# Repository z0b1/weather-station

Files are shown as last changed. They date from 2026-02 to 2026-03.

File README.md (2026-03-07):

# weather-station
I'm presenting my project of a Field Weather Station containing anemometers and wind direction sensors, also ambient temp. and humidity sensors with a UHF transmitter in the field and an at home reciever(rtl-sdr). This also includes an RPi 4 (4GB RAM) that is recieving satellite images and displaying them in a mobile phone app.
# Why a weather station-Short Story
I live in the countryside and my family has large fruit plantations. By the microclimate of my area strong frosts in the spring time are common, that quite often hurts the fruits. We solve this issue by turning on our watering systems(the ground water keeps around 12 degrees Celsius at all times), but also by using air heaters to warm the area. So instead of waking up every 30 minutes to check the temps and having to go outside this idea was born. Main goal is that the weather station sends me phone notifications to a custom website/app. The weather station is located atleast 500m away from the house so the trick was getting reliable power, which I solved using a solar panel and a Lead Acid battery.
# How it functions 
Using an Arduino Nano I read the data from the sensors and send it with my UHF transmitter using ASK modulation(to be changed to FSK if too much interferences). At home using a reciever and an RPi 4 Model B (4GB), RTL SDR V4 and a homemade quadrifillar helix antenna to recieve satellite images and a Nagoya antenna for the UHF signals. Compare it and display on the website/app using the RPi.
# What might be added 
Using local LLM's to recognize cloud and other patterns to predict weather more accurately.

# Pictures
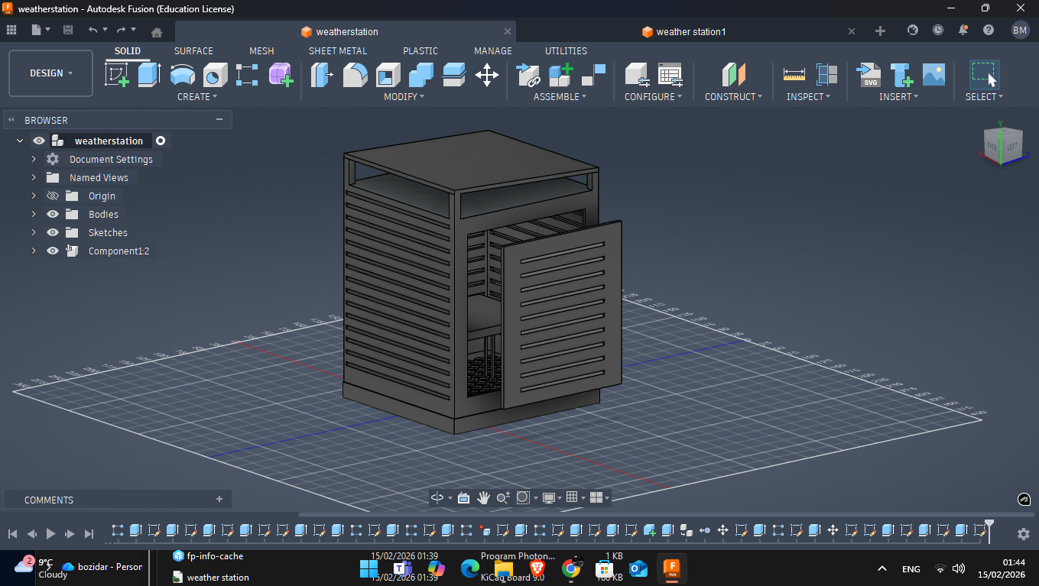
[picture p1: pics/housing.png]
housing

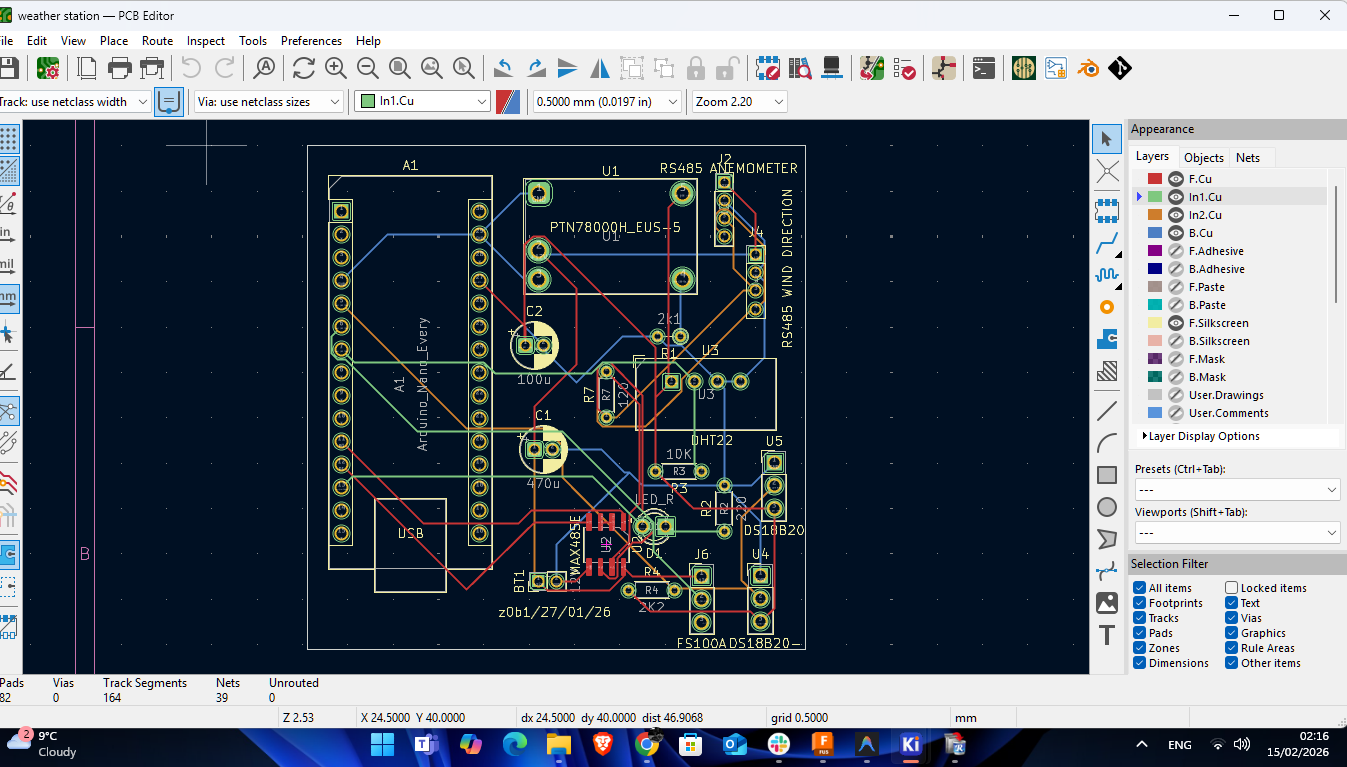
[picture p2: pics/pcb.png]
pcb

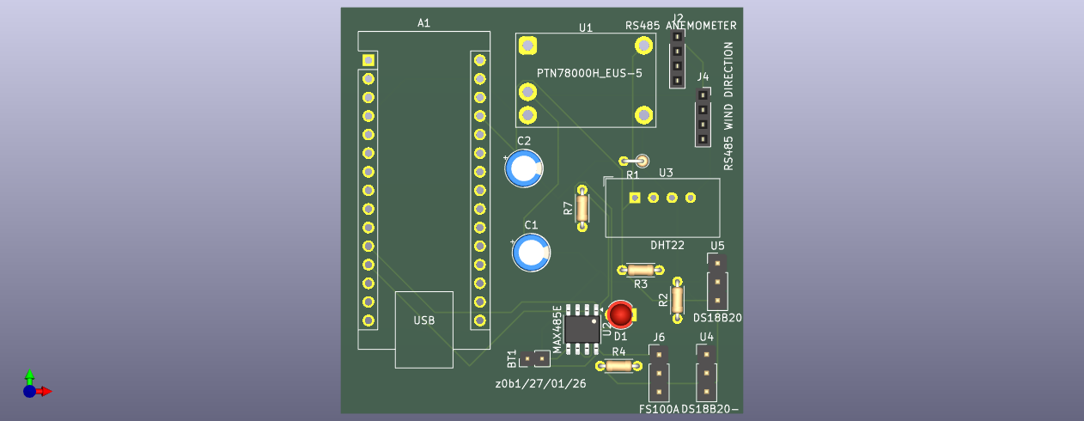
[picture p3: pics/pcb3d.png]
pcb3d


# NAPRED ZVEZDO

# The BOM

| Reference | Qty | Value | Price | Link | Info | Datasheet |
|---|---|---|---|---|---|---|
| A1 | 1 | Arduino Nano | € 5.16 | [Link](https://www.aliexpress.com/item/1005009848194286.html) | | [Link](https://content.arduino.cc/assets/NANOEveryV3.0_sch.pdf) |
| AE1 | 1 | Antenna Shielded SMA | € 0.00 | [Link](https://www.aliexpress.com/item/1005008813991595.html) | I already have | ~ |
| AE2 | 2 | Nagoya NA-771 | € 7.47 | [Link](https://www.aliexpress.com/item/1005008660133810.html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) | High Gain Handheld Antenna | ~ |
| BT1 | 1 | 12V 5Ah Lead Acid | € 11.84 | [Link](https://borikplus.rs/proizvodi/olovne-baterije/ritar-rt1250-olovna-vrla-baterija-12v-5ah/) | Alternative capacity | ~ |
| C1 | 1 | 470uF | € 0.00 | [Link](https://www.aliexpress.com/item/1005008244407175.html) | I already have | ~ |
| C2 | 1 | 100uF | € 0.00 | [Link](https://www.aliexpress.com/item/1005005661484224.html) | I already have | ~ |
| C3 | 1 | 2pF | - | | | ~ |
| C4 | 1 | 2.2pF | - | | | ~ |
| C5 | 1 | 10pF | - | | | ~ |
| C6 | 1 | 470pF | - | | | ~ |
| D1 | 1 | LED_R | € 0.00 | [Link](https://www.aliexpress.com/item/1005010315277808.html) | I already have | ~ |
| J1, J2 | 1 | RS485 ANEMOMETER | € 26.53 | [Link](https://www.aliexpress.com/item/1005007059408469.html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) | RS485 type | ~ |
| J4 | 1 | RS485 WIND DIRECTION | € 23.82 | [Link](https://www.aliexpress.com/item/1005007059408469.html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) | RS485 type | ~ |
| U4 | 1 | SDLA12TA | € 6.86 | [Link](https://www.aliexpress.com/item/1005006641063540.html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) | | [Link](https://easyeda.com/component/451d05428ff8431fb9c594829dfd0fbf) |
| R1 | 1 | 2k1 | € 0.00 | [Link](https://www.aliexpress.com/item/1005010688244614.html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) | I already have | ~ |
| R2 | 1 | 220| - | | | ~ |
| R3, R6 | 2 | 10K | - | | | ~ |
| R5 | 1 | 47K | - | | | ~ |
| R7 | 1 | 120 | - | | | ~ |
| SC1 | 1 | Solar cell | € 23.00 | [Link]([(https://www.aliexpress.com/item/1005009242077484.html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)]) | 15W 12V | ~ |
| U1 | 1 | DC-DC Buck Converter PTN78000HAZ | € 3.02 | [Link](https://www.aliexpress.com/item/1005008535110639.html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) | Voltage Regulator | ~ |
| U2 | 1 | MAX485E | € 4.39 | [Link](https://www.aliexpress.com/item/1005008248138246.html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) | RS485 Translate | [Link](https://datasheets.maximintegrated.com/en/ds/MAX1487E-MAX491E.pdf) |
| U3 | 1 | DHT22 | € 3.01 | [Link](https://www.aliexpress.com/item/1005012000000000.html) | Temp & Humidity sensor | [Link](http://akizukidenshi.com/download/ds/aosong/AM2302.pdf) |
| RF1 | 1 | 433MHz RF Kit | € 0.00 | [Link](https://www.aliexpress.com/item/1005005853468512.html) | Transmitter + Receiver(i already have) | |
| U5 | 2 | DS18B20 | € 5.59 | [Link](https://www.aliexpress.com/item/1005010363252763.html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) | Waterproof Temp Sensor | [Link](https://datasheets.maximintegrated.com/en/ds/DS18B20.pdf) |
| U6 | 1 | Raspberry Pi 4 Model B (4GB) | € 82.56 | [Link](https://www.aliexpress.com/item/1005012300000000.html) | Receiver Host | ~ |
| U7 | 1 | RTL-SDR V4 | € 35.39 | [Link](https://www.aliexpress.com/item/1005005952682051.html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) | Official Receiver | ~ |
| AC1 | 1 | Micro-Type Diplexer Duplex Filter | € 11.09 | [Link](https://www.aliexpress.com/item/1005005862057777.html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) | 10W V/U 2m 70cm | ~ |
| PCB | 1 | JLCPCB PCB Manufacturing | € 19.61 | [Link]| $20.75 | ~ |

**Grand Total**: € 269.34 ($ 285.50)  
**Grand Total (Including shipping/VAT)**: € 274.87 ($ 291.36)

**NOTE: IN THE GRAND TOTAL IS INCLUDED THE PRICE OF JLCPCB PCB MANUFACTURING**

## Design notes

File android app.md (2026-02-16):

# Weather Station Android App

## Open in Android Studio
 Launch **Android Studio**.
 Go to **File > Open**.
 Navigate to and select the `firmware/AndroidApp` folder.
 Wait for Gradle to sync.

## Configure the Backend URL
 Open `app/src/main/java/com/z0b1/weatherstation/MainActivity.kt`.
 Locate the `baseUrl` variable.
 Replace the placeholder with your **zrok** reserved public URL:
   ```kotlin
   val baseUrl = "https://your-name.share.zrok.io"
   ```

### Build & Install
 Connect your Android phone via USB (with Developer Mode and USB Debugging enabled).
 Click the Run (green triangle) button in Android Studio.
 The app will install and start fetching live data from your Raspberry Pi.
 Or download the APK from the APK folder.

## Features
- Live Monitoring: Real-time Temperature and Humidity.
- Wind Analytics: Visual compass for wind direction and speed.
- Satellite Gallery: View the latest images captured by your RTL-SDR.
- Frost Alerts: Automatic notifications when temperature drops below 1°C.
- Background Sync: Updates every 10 seconds while active.

## Internet Access (zrok)
1. Install **zrok** on your Raspberry Pi.
2. Run the following command to share your API (port 8000) publicly:
   ```bash
   zrok share public http://localhost:8000 --backend-mode proxy
   ```
3. Copy the URL provided by zrok and paste it into `MainActivity.kt`.

## Customizing Icons

### Dashboard Icons
The icons for stats (Temperature, Humidity, etc.) are implemented using **Material Icons** in `MainActivity.kt`. You can change them by modifying the `icon` parameter in the `StatCard` calls.

### Launcher Icon (App Logo)
To change the app's main icon:
1.  Open the project in **Android Studio**.
2.  Right-click the **app** folder -> **New > Image Asset**.
3.  Select **Launcher Icons (Adaptive and Legacy)**.
4.  Pick your image/SVG in the **Path** field.
5.  Scale it to fit the safe zone.
6.  Finish the wizard; Android Studio handles all sizes for you.

---
## NAPRED ZVEZDO

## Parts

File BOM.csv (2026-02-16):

Reference | Qty | Value | Price | Link | Info | Datasheet
A1 | 1 | Arduino Nano | € 5.16 | https://www.aliexpress.com/item/1005009848194286.html |  | https://content.arduino.cc/assets/NANOEveryV3.0_sch.pdf
AE1 | 1 | Antenna Shielded SMA | € 0.00 | https://www.aliexpress.com/item/1005008813991595.html | I already have | ~
AE2 | 2 | Nagoya NA-771 | € 7.47 | https://www.aliexpress.com/item/1005008660133810.html?curPageLogUid=peroKELiN18w | High Gain Handheld Antenna | ~
BT1 | 1 | 12V 5Ah Lead Acid | € 11.84 | https://borikplus.rs/proizvodi/olovne-baterije/ritar-rt1250-olovna-vrla-baterija-12v-5ah/ | Alternative capacity | ~
C1 | 1 | 470uF | € 0.00 | https://www.aliexpress.com/item/1005008244407175.html | I already have | ~
C2 | 1 | 100uF | € 0.00 | https://www.aliexpress.com/item/1005005661484224.html | I already have | ~
C3 | 1 | 2pF | - |  |  | ~
C4 | 1 | 2.2pF | - |  |  | ~
C5 | 1 | 10pF | - |  |  | ~
C6 | 1 | 470pF | - |  |  | ~
D1 | 1 | LED_R | € 0.00 | https://www.aliexpress.com/item/1005010315277808.html | I already have | ~
J1,J2 | 1 | RS485 ANEMOMETER | € 26.53 | https://www.aliexpress.com/item/1005007059408469.html | RS485 type | ~
J4 | 1 | RS485 WIND DIRECTION | € 23.82 | https://www.aliexpress.com/item/1005007059408469.html | RS485 type | ~
U4 | 1 | SDLA12TA | € 6.86 | https://www.aliexpress.com/item/1005006641063540.html |  | https://easyeda.com/component/451d05428ff8431fb9c594829dfd0fbf
R1 | 1 | 2k1? | € 0.00 | https://www.aliexpress.com/item/1005010688244614.html | I already have | ~
R2 | 1 | 220? | - |  |  | ~
R3 | R6 | 2 | 10K? | - |  |  | ~
R5 | 1 | 47K? | - |  |  | ~
R7 | 1 | 120? | - |  |  | ~
SC1 | 1 | Solar cell | € 23.00 | https://www.xunzel.com/store/en/producto/solarpower-15w-12v/ | 15W 12V | ~
U1 | 1 | DC-DC Buck Converter PTN78000HAZ | € 3.02 | https://www.aliexpress.com/item/1005008535110639.html?curPageLogUid=FJqewnV1My1f | Voltage Regulator | ~
U2 | 1 | MAX485E | € 4.39 | https://www.aliexpress.com/item/1005008248138246.html?curPageLogUid=iT1tcIOUDtud | RS485 Translate | https://datasheets.maximintegrated.com/en/ds/MAX1487E-MAX491E.pdf
U3 | 1 | DHT22 | € 3.01 | https://www.aliexpress.com/item/1005012000000000.html | Temp & Humidity sensor | http://akizukidenshi.com/download/ds/aosong/AM2302.pdf
RF1 | 1 | 433MHz RF Kit | € 0.00 | https://www.aliexpress.com/item/1005005853468512.html | I already have | ~
U5 | 2 | DS18B20 | € 5.59 | https://www.aliexpress.com/item/1005010363252763.html?curPageLogUid=zeX5XbhmfOld | Waterproof Temp Sensor | https://datasheets.maximintegrated.com/en/ds/DS18B20.pdf
U6 | 1 | Raspberry Pi 4 Model B (4GB) | € 82.56 | https://www.aliexpress.com/item/1005012300000000.html | Receiver Host | ~
U7 | 1 | RTL-SDR Blog V4 | € 35.39 | https://www.rtl-sdr.com/buy-rtl-sdr-dvb-t-dongles/ | Official Receiver | ~
AC1 | 1 | Micro-Type Diplexer Duplex Filter | € 11.09 | https://www.aliexpress.com/item/1005005862057777.html | 10W V/U 2m 70cm | ~
PCB | 1 | JLCPCB PCB Manufacturing | € 19.61 | https://jlcpcb.com/ | $20.75 Including Shipping | ~
 | Grand Total | Including shipping and VAT
 | € 269.34 | € 274.87
 | $285.50 | $291.36

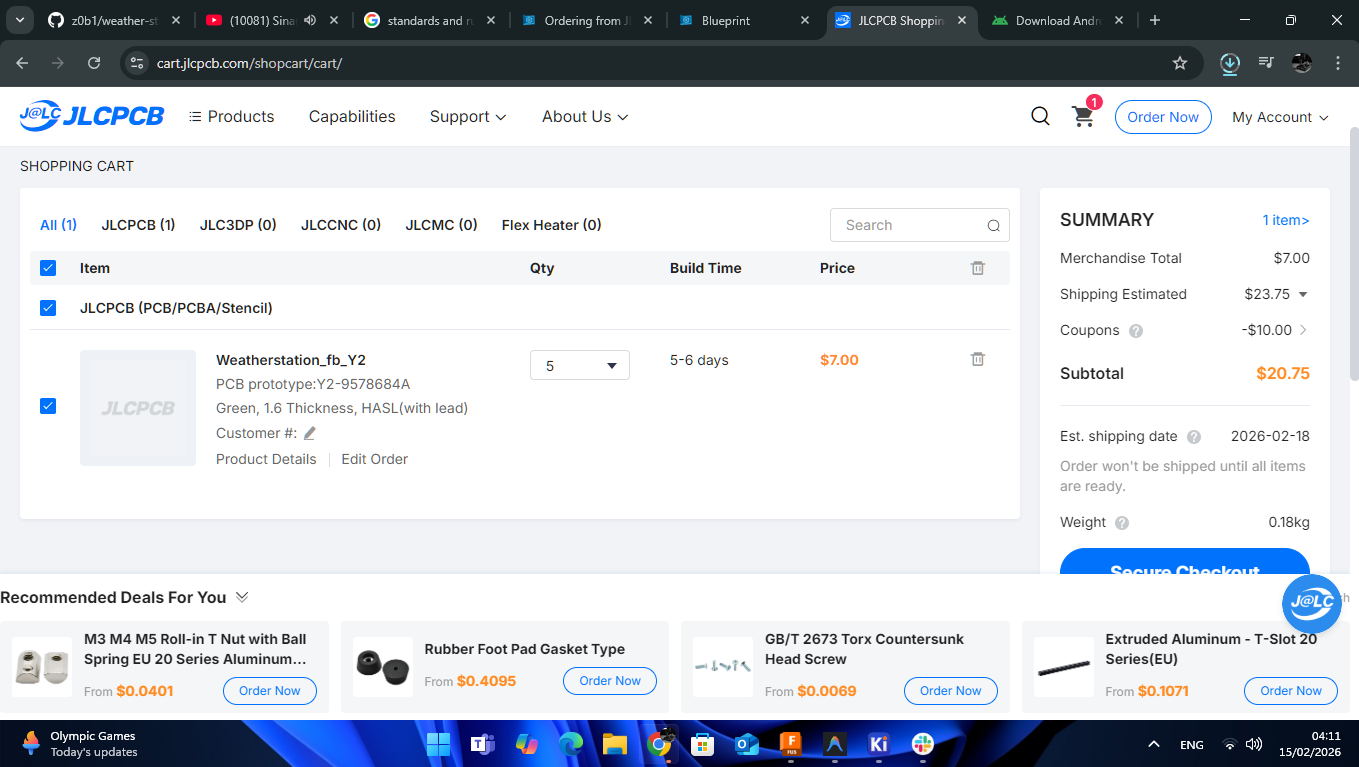
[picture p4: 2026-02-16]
KiCAD/jlcpcbsc/jlcpcb order.png

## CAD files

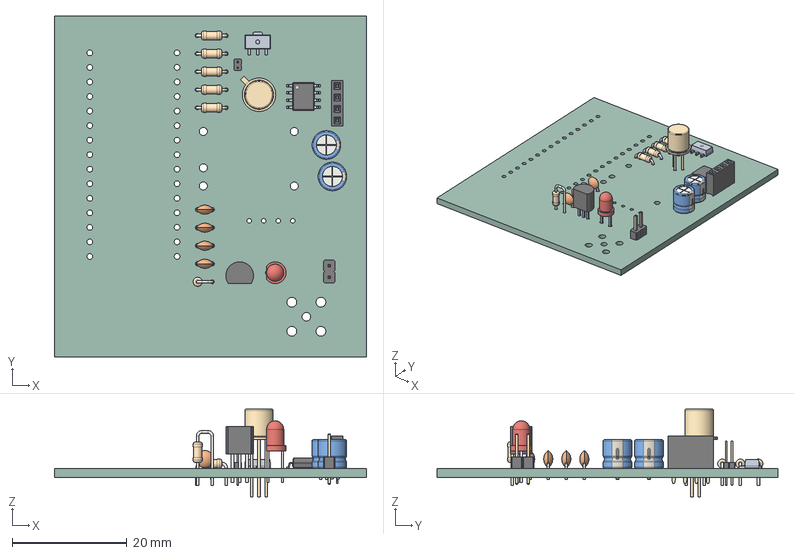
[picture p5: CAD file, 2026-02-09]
KiCAD/weather station/weather station.step
54.5 x 59.5 x 15.3 mm
C_Disc_D3.0mm_W1.6mm_P2.50mm x 4
R_Axial_DIN0204_L3.6mm_D1.6mm_P5.08mm_Horizontal x 5
SOIC-8_3.9x4.9mm_P1.27mm
weather station 1.4.1
PinHeader_1x02_P2.00mm_Vertical
TO-92_Inline
TO-18-3
R_Axial_DIN0204_L3.6mm_D1.6mm_P2.54mm_Vertical
LED_D3.0mm
PinHeader_1x02_P1.00mm_Vertical
PinSocket_1x04_P2.00mm_Vertical
CP_Radial_D5.0mm_P2.00mm x 2
weather station_PCB

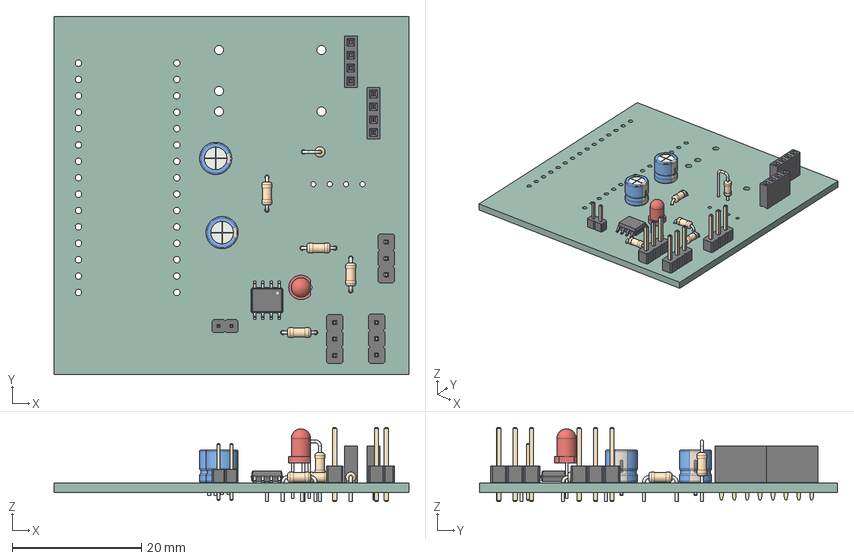
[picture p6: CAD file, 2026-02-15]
production/PCB.step
55.0 x 55.5 x 11.5 mm
PinHeader_1x03_P2.54mm_Vertical x 3
PinHeader_1x02_P2.00mm_Vertical
CP_Radial_D5.0mm_P2.00mm x 2
R_Axial_DIN0204_L3.6mm_D1.6mm_P5.08mm_Horizontal x 4
R_Axial_DIN0204_L3.6mm_D1.6mm_P2.54mm_Vertical
PinSocket_1x04_P2.00mm_Vertical x 2
LED_D3.0mm
SOIC-8_3.9x4.9mm_P1.27mm
weather station_PCB

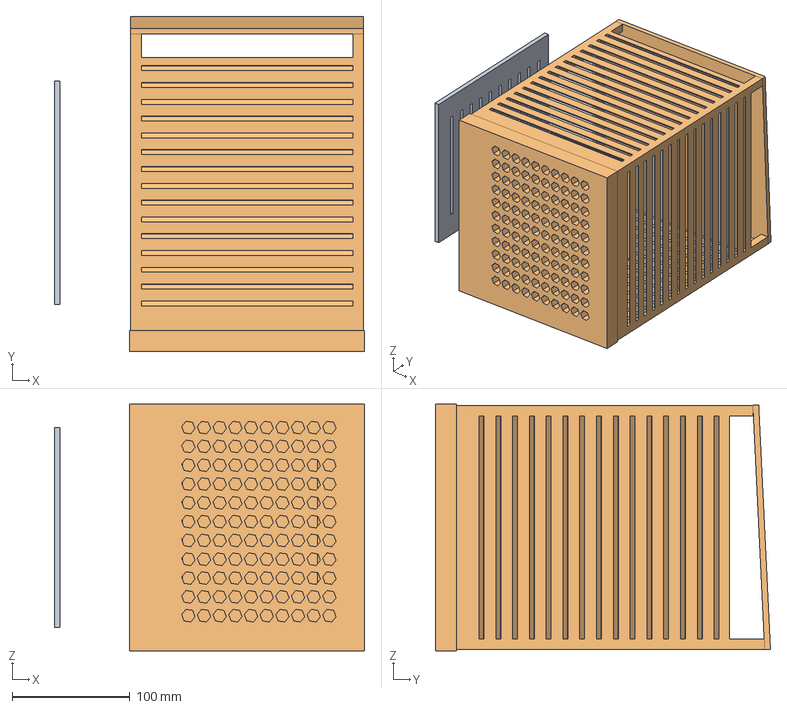
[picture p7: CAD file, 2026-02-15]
production/housing.step
264.0 x 285.0 x 210.0 mm

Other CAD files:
3D models/housing.f3d

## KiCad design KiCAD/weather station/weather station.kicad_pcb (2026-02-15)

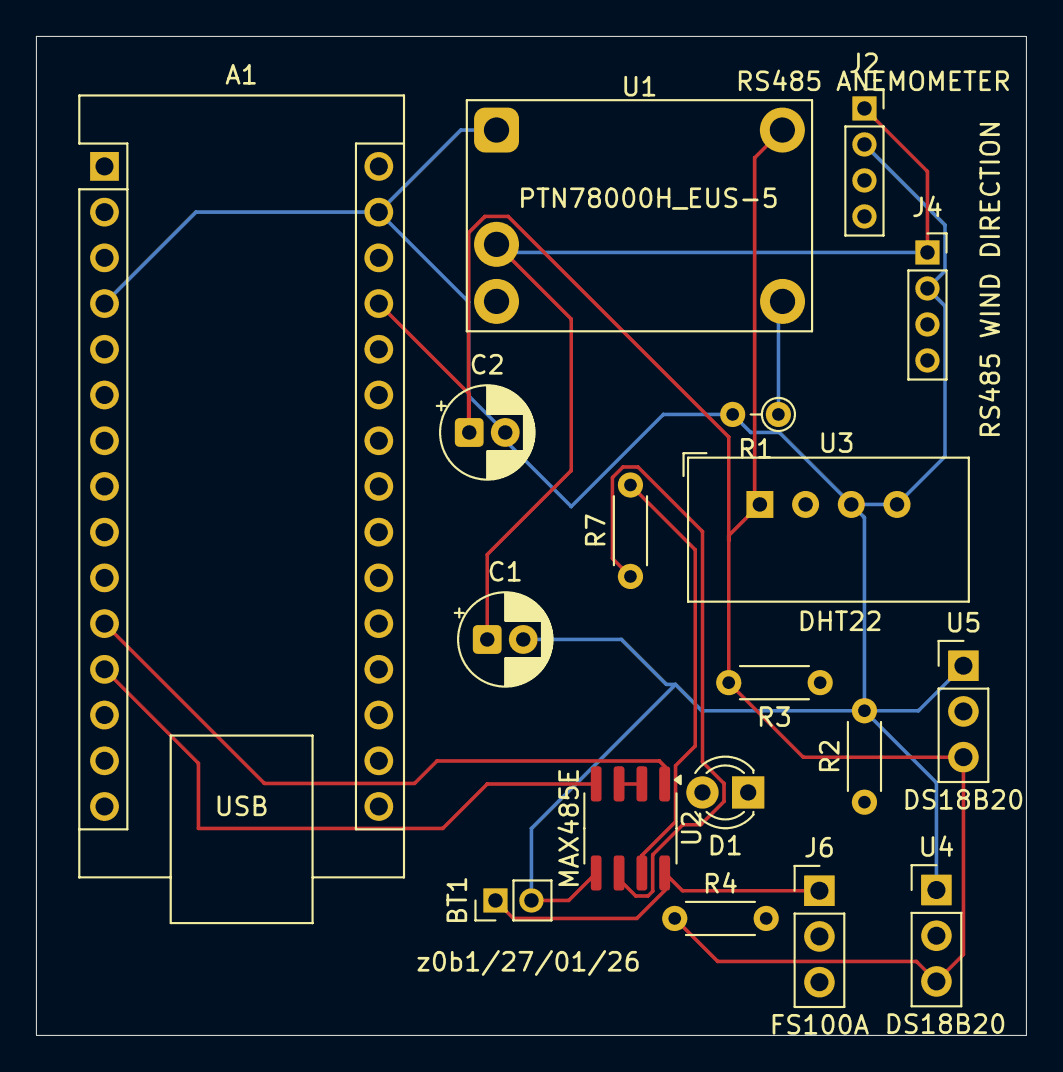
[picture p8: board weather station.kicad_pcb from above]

Board: 4 copper layers, 55.0 x 55.5 mm, 18 parts (0 on the bottom side), 14 nets.

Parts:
A1: Arduino_Nano_Every; Arduino_Nano
BT1: 12V; PinHeader_1x02_P2.00mm_Vertical
C1: 470u; CP_Radial_D5.0mm_P2.00mm
C2: 100u; CP_Radial_D5.0mm_P2.00mm
D1: LED_R; LED_D3.0mm
J2: RS485 ANEMOMETER; PinSocket_1x04_P2.00mm_Vertical
J4: RS485 WIND DIRECTION; PinSocket_1x04_P2.00mm_Vertical
J6: FS100A; PinHeader_1x03_P2.54mm_Vertical
R1: 2k1; R_Axial_DIN0204_L3.6mm_D1.6mm_P2.54mm_Vertical
R2: 220; R_Axial_DIN0204_L3.6mm_D1.6mm_P5.08mm_Horizontal
R3: 10K; R_Axial_DIN0204_L3.6mm_D1.6mm_P5.08mm_Horizontal
R4: 2K2; R_Axial_DIN0204_L3.6mm_D1.6mm_P5.08mm_Horizontal
R7: 120; R_Axial_DIN0204_L3.6mm_D1.6mm_P5.08mm_Horizontal
U1: PTN78000H_EUS-5; Texas_EUS_R-PDSS-T5_THT
U2: MAX485E; SOIC-8_3.9x4.9mm_P1.27mm
U3: DHT22; ASAIR_AM2302_P2.54mm_Vertical
U4, U5: DS18B20; PinHeader_1x03_P2.54mm_Vertical

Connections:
+12V: BT1.1 (+), C1.1, J2.1, J4.1, J6.1, U1.2 (VI), U2.8 (VCC)
A+: J2.3, J4.3, R7.1, U2.6 (A)
B-: J2.4, J4.4, R7.2, U2.7 (B)
D8: A1.11 (D8), U2.1 (RO)
D9: A1.12 (D9), U2.4 (DI)
GND: A1.4 (GND), A1.29 (GND), BT1.2 (-), C1.2, C2.2, J2.2, J4.2, R1.2, R2.2, U1.1 (GND), U2.5 (GND), U3.3 (GND), U3.4 (GND), U4.1 (GND), U5.1 (GND)
unnamed: A1.27 (+5V), C2.1, R3.2, R4.1, U1.5 (VO), U3.1 (VDD), U4.3 (V_{DD}), U5.3 (V_{DD})
unnamed: A1.5 (D2), R4.2, U4.2 (DQ), U5.2 (DQ)
unnamed: A1.6 (D3), J6.2
unnamed: A1.7 (D4), R3.1, U3.2 (SDA)
unnamed: A1.13 (D10), D1.2 (A)
unnamed: D1.1 (K), R2.1
unnamed: R1.1, U1.4 (Vo_Adj)
unnamed: U2.2 (~RE), U2.3 (DE)

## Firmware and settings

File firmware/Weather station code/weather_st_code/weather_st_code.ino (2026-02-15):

/*
 * DIY Solar Weather Station - Hack Club Blueprint 2026
 * Setup: Arduino Nano + RS485 Anemometers + DHT22
 * Radio: FS1000A 433.92MHz Transmitter
 * By: z0b1
 */

#include "DHT.h"
#include <DallasTemperature.h>
#include <ModbusMaster.h>
#include <OneWire.h>
#include <RH_ASK.h>
#include <SPI.h>
#include <SoftwareSerial.h>

#define DHT_PIN 4 // DHT22 data line
#define DHT_TYPE DHT22
#define ONE_WIRE_BUS 2 // DS18B20 on D2
#define RS485_RX 8     // MAX485 Receive (RO)
#define RS485_TX 9     // MAX485 Transmit (DI)
#define RS485_CONTROL 5
#define RF_TX_PIN 3   // FS1000A Data pin
#define STATUS_LED 10 // Blinks during transmission

#define SPEED_ID 1
#define DIRECTION_ID 2

DHT dht(DHT_PIN, DHT_TYPE);
SoftwareSerial rs485Serial(RS485_RX, RS485_TX);
ModbusMaster modbus;
RH_ASK driver(2000, 0, RF_TX_PIN, 0);

OneWire oneWire(ONE_WIRE_BUS);
DallasTemperature sensors(&oneWire);

float windSpeed = 0.0;
int windHeading = 0;
float airTemp = 0.0;
float airHum = 0.0;
float soilTemp = 0.0;
float surfTemp = 0.0;

// RS485 mode
void toggleRS485(bool transmit) {
  digitalWrite(RS485_CONTROL, transmit ? HIGH : LOW);
  delay(5);
}

void setup() {
  Serial.begin(9600);
  rs485Serial.begin(9600);
  dht.begin();
  sensors.begin();

  if (!driver.init()) {
    Serial.println("RadioHead init failed");
  }

  pinMode(RS485_CONTROL, OUTPUT);
  pinMode(STATUS_LED, OUTPUT);

  toggleRS485(false);
  modbus.preTransmission([]() { toggleRS485(true); });
  modbus.postTransmission([]() { toggleRS485(false); });
}

void loop() {
  // read dht22
  airTemp = dht.readTemperature();
  airHum = dht.readHumidity();

  // read ground sensors
  sensors.requestTemperatures();
  soilTemp = sensors.getTempCByIndex(0); // 10cm below
  surfTemp = sensors.getTempCByIndex(1); // 10cm above

  // read speed
  modbus.begin(SPEED_ID, rs485Serial);
  if (modbus.readHoldingRegisters(0x0000, 1) == modbus.ku8MBSuccess) {
    windSpeed = modbus.getResponseBuffer(0) / 10.0;
  }

  // read direction
  modbus.begin(DIRECTION_ID, rs485Serial);
  if (modbus.readHoldingRegisters(0x0000, 1) == modbus.ku8MBSuccess) {
    windHeading = modbus.getResponseBuffer(0);
  }

  // send data
  sendRadioPacket();
  delay(5000);
}

// radio transmitter
void sendRadioPacket() {
  digitalWrite(STATUS_LED, HIGH);

  // build payload
  String payload = "S:" + String(windSpeed, 1) + ",D:" + String(windHeading) +
                   ",T:" + String(airTemp, 1) + ",H:" + String(airHum, 0) +
                   ",ST:" + String(soilTemp, 1) + ",SU:" + String(surfTemp, 1) +
                   ";";

  const char *msg = payload.c_str();
  driver.send((uint8_t *)msg, strlen(msg));
  driver.waitPacketSent();

  digitalWrite(STATUS_LED, LOW);
}

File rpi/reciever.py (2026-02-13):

import subprocess
import json
import csv
import os
import datetime
import time
import signal
try:
    import RPi.GPIO as GPIO
except ImportError:
    # mock for pc
    class GPIO:
        BCM = BOARD = OUT = HIGH = LOW = 0
        @staticmethod
        def setmode(a): pass
        @staticmethod
        def setup(a, b): pass
        @staticmethod
        def output(a, b): pass
        @staticmethod
        def cleanup(): pass

from tracker import SatelliteTracker

# config
CSV_FILE = "weather_data.csv"
SDR_FREQUENCY = "433.92M"
ANTENNA_SWITCH_PIN = 17

# satellite setup
SAT_CONFIG = {
    "meteor-m2 3": {"freq": "137.100M", "pipeline": "meteor_m2_lrpt"},
    "meteor-m2 4": {"freq": "137.900M", "pipeline": "meteor_m2_lrpt"}
}

# rtl_433 command
DECODER_COMMAND = [
    "rtl_433",
    "-f", SDR_FREQUENCY,
    "-M", "json",
    "-X", "n=WeatherStation,m=OOK_PWM,s=250,l=600,g=400,r=2000,bits>=40",
    "-F", "json"
]

class WeatherSDR:
    def __init__(self):
        self.process = None
        self.is_satellite_recording = False
        self.tracker = SatelliteTracker()
    
    # setup pins
    GPIO.setmode(GPIO.BCM)
    GPIO.setup(ANTENNA_SWITCH_PIN, GPIO.OUT)
    self.set_antenna_mode('weather')

    def set_antenna_mode(self, mode):
        """switch relay mode"""
        if mode == 'sat':
            print("[*] switching to sat")
            GPIO.output(ANTENNA_SWITCH_PIN, GPIO.HIGH)
        else:
            print("[*] switching to weather")
            GPIO.output(ANTENNA_SWITCH_PIN, GPIO.LOW)
        time.sleep(1)
        
    def start_receiver(self):
        print(f"[*] starting receiver on {SDR_FREQUENCY}")
        self.process = subprocess.Popen(
            DECODER_COMMAND,
            stdout=subprocess.PIPE,
            stderr=subprocess.DEVNULL,
            universal_newlines=True
        )

    def stop_receiver(self):
        if self.process:
            print("[*] stopping receiver")
            self.process.terminate()
            self.process.wait()
            self.process = None

    def record_satellite(self, sat_info):
        """record satellite pass"""
        self.set_antenna_mode('sat')
        
        sat_name = sat_info['name'].lower()
        config = None
        for key in SAT_CONFIG:
            if key in sat_name:
                config = SAT_CONFIG[key]
                break
        
        if not config:
            config = {"freq": "137.100M", "pipeline": "meteor_m2_lrpt"}

        now_str = datetime.datetime.now().strftime("%Y%m%d_%H%M%S")
        output_dir = os.path.join("recordings", f"{sat_name.replace(' ', '_')}_{now_str}")
        os.makedirs(output_dir, exist_ok=True)

        cmd = [
            "satdump", config["pipeline"], "iqn",
            "--source", "rtl_sdr",
            "--samplerate", "1.024e6",
            "--frequency", config["freq"],
            "--gain", "45",
            "--path", output_dir,
            "--timeout", "60"
        ]

        print(f"[!] recording {sat_name.upper()}")
        try:
            subprocess.run(cmd, timeout=1800)
            print(f"[+] done. saved to {output_dir}")
        except Exception as e:
            print(f"[!] error: {e}")
        finally:
            # resume weather mode
            self.set_antenna_mode('weather')

    def hex_to_string(self, hex_str):
        try:
            bytes_data = bytes.fromhex(hex_str)
            return bytes_data.decode('ascii', errors='ignore')
        except:
            return None

    def save_data(self, packet):
        """log to csv"""
        now = datetime.datetime.now().strftime("%Y-%m-%d %H:%M:%S")
        packet = packet.split(';')[0] + ';'
        print(f"[{now}] {packet}")
        
        try:
            parts = packet.replace(';', '').split(',')
            row = [now] + [p.split(':')[-1] for p in parts]
            
            file_exists = os.path.isfile(CSV_FILE)
            with open(CSV_FILE, 'a', newline='') as f:
                writer = csv.writer(f)
                if not file_exists:
                    # add header if new file
                    writer.writerow(["Timestamp", "Speed", "Heading", "Temp", "Hum"])
                writer.writerow(row)
        except:
            pass

    def run(self):
        self.start_receiver()
        
        try:
            while True:
                # check for satellites
                active_pass = self.tracker.is_pass_active(min_elevation=5)
                
                if active_pass and not self.is_satellite_recording:
                    self.stop_receiver()
                    self.is_satellite_recording = True
                    self.record_satellite(active_pass)
                    self.is_satellite_recording = False
                    self.start_receiver()

                # read rtl_433 output
                if self.process:
                    line = self.process.stdout.readline()
                    if line:
                        try:
                            data = json.loads(line)
                            if "codes" in data:
                                raw_hex = data["codes"][0]
                                payload = self.hex_to_string(raw_hex)
                                if payload and "S:" in payload:
                                    self.save_data(payload)
                        except json.JSONDecodeError:
                            continue

                time.sleep(0.1)
        except KeyboardInterrupt:
            # cleanup on exit
            self.stop_receiver()
            GPIO.cleanup()

if __name__ == "__main__":
    receiver = WeatherSDR()
    receiver.run()

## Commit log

2026-01-27 Add BOM section to README
    Added a section for the Bill of Materials (BOM) in the README.
2026-02-15 PCB update and firmware update
    [PCB.step, freerouting.dsn, housing.step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]
2026-02-15 PCB PNG
2026-02-15 refining the code and changing from OOK to ASK
    [PCB.step, housing.f3d, housing.step]
2026-02-15 made the BOM table in the readme
2026-02-15 Updating BOM
    [BOM.csv]
2026-02-15 Optimized the BOM and the tracking code, should work with ntfy.sh
    [BOM.csv]
2026-02-15 Android app developing and a tutorial for when i connect the rpi to the app
    [@home.kicad_sch, weather station.kicad_pcb, weather station.kicad_sch]
2026-02-15 Added a 10cm below and above temp sensors(standard for agricultural meteorology)
2026-02-16 BOM change
2026-02-16 Finalized the BOM
    [BOM.csv]
2026-02-20 added some features and fixed indent issues
    [reciever.py]
2026-03-07 Moved the BOM to the bottom of the readme
